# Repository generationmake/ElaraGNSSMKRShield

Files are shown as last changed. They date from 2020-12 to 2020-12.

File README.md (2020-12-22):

# ElaraGNSSMKRShield
GNSS Shield with Wuerth Elara for Arduino MKR

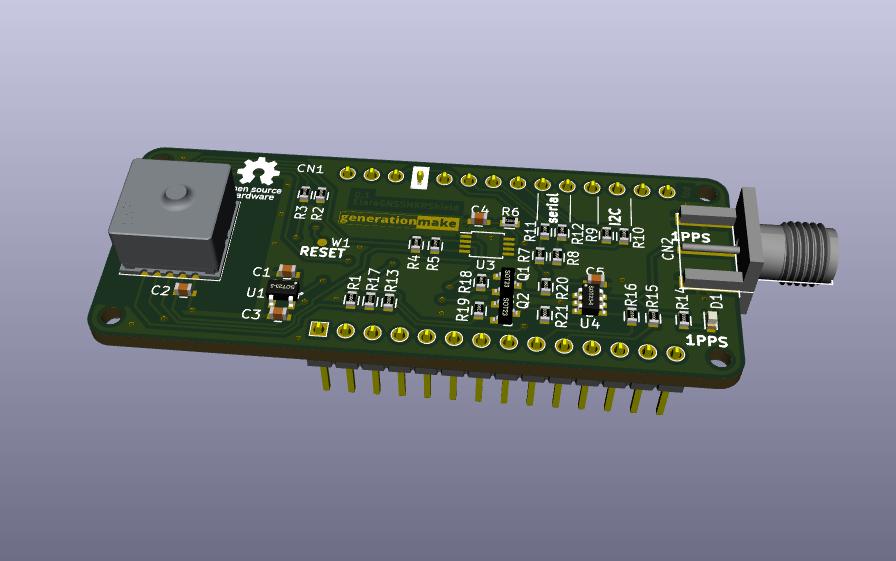
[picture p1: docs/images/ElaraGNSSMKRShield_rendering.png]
ElaraGNSSMKRShield rendering


## pin usage

### Arduino MKR connector CN1

| **Pin** | **Pin Name** | **Signal** | **Description** |
|:---:|:---:|:---:|:---:|
| 1 | AREF | | |
| 2 | DAC0/A0 | | |
| 3 | A1 | | |
| 4 | A2 | | |
| 5 | A3 | | |
| 6 | A4 | | |
| 7 | A5 | | |
| 8 | A6 | | |
| 9 | 0 | WAKE_UP | wake signal to Elara GNSS |
| 10 | 1 | 1PPS | 1PPS signal from Elara GNSS |
| 11 | 2 | | |
| 12 | 3 | | |
| 13 | 4 | | |
| 14 | 5 | ON_OFF | switch Elara GNSS on and off |
| 15 | 6 | | |
| 16 | 7 | | |
| 17 | 8/MOSI | | |
| 18 | 9/SCK | | |
| 19 | 10/MISO | | |
| 20 | 11/SDA | I2C_SDA | to Elara GNSS if I2C option is used |
| 21 | 12/SCL | I2C_SCL | to Elara GNSS if I2C option is used |
| 22 | 13/RX | SERIAL_RX | to Elara GNSS if serial option is used |
| 23 | 14/TX | SERIAL_TX | to Elara GNSS if serial option is used |
| 24 | RESET | | |
| 25 | GND | GND | |
| 26 | VCC | 3V3-rail | supply voltage for board |
| 27 | VIN | | |
| 28 | 5V0 | | |

### SMA connector CN2

SMA coax connector.

| **Pin** | **Signal** | **Description** |
|:---:|:---:|:---:|
| center  | 1PPS | |
| shield  | GND | |

## PCB

### Top

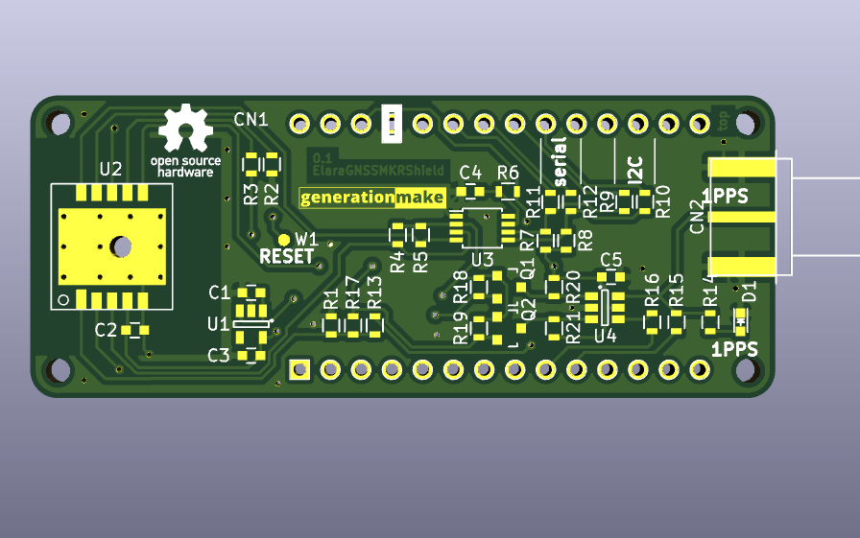
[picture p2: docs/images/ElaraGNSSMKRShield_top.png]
ElaraGNSSMKRShield PCB top


### Bottom

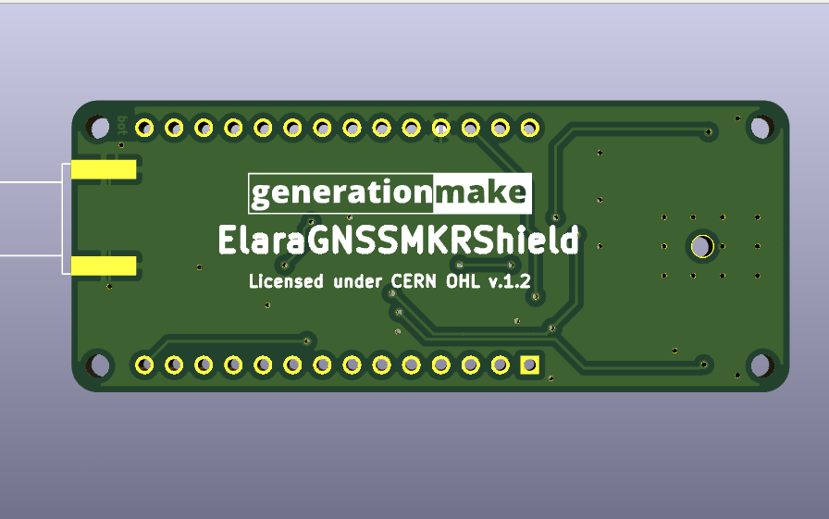
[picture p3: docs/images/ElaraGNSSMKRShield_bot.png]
ElaraGNSSMKRShield PCB bot


## Variants

By default the Elara GNSS is connected via I2C. It is possible to connect to serial.

### BOM changes

The following parts need to be changed:

| part | I2C variant | serial variant |
|:----:|:---:|:---:|
| R2 | 10k | DNI |
| R3 | DNI | 10k |
| R9 | 0R | DNI |
| R10  | 0R | DNI |
| R11  | DNI | 0R |
| R12  | DNI | 0R |

## Resources

### Datasheets

 * https://www.we-online.de/katalog/de/ELARA-I
 
 ### Arduino Libraries

* [107-Arduino-NMEA-Parser](https://github.com/107-systems/107-Arduino-NMEA-Parser)

## License

This hardware is licensed under the CERN OHL v. 1.2

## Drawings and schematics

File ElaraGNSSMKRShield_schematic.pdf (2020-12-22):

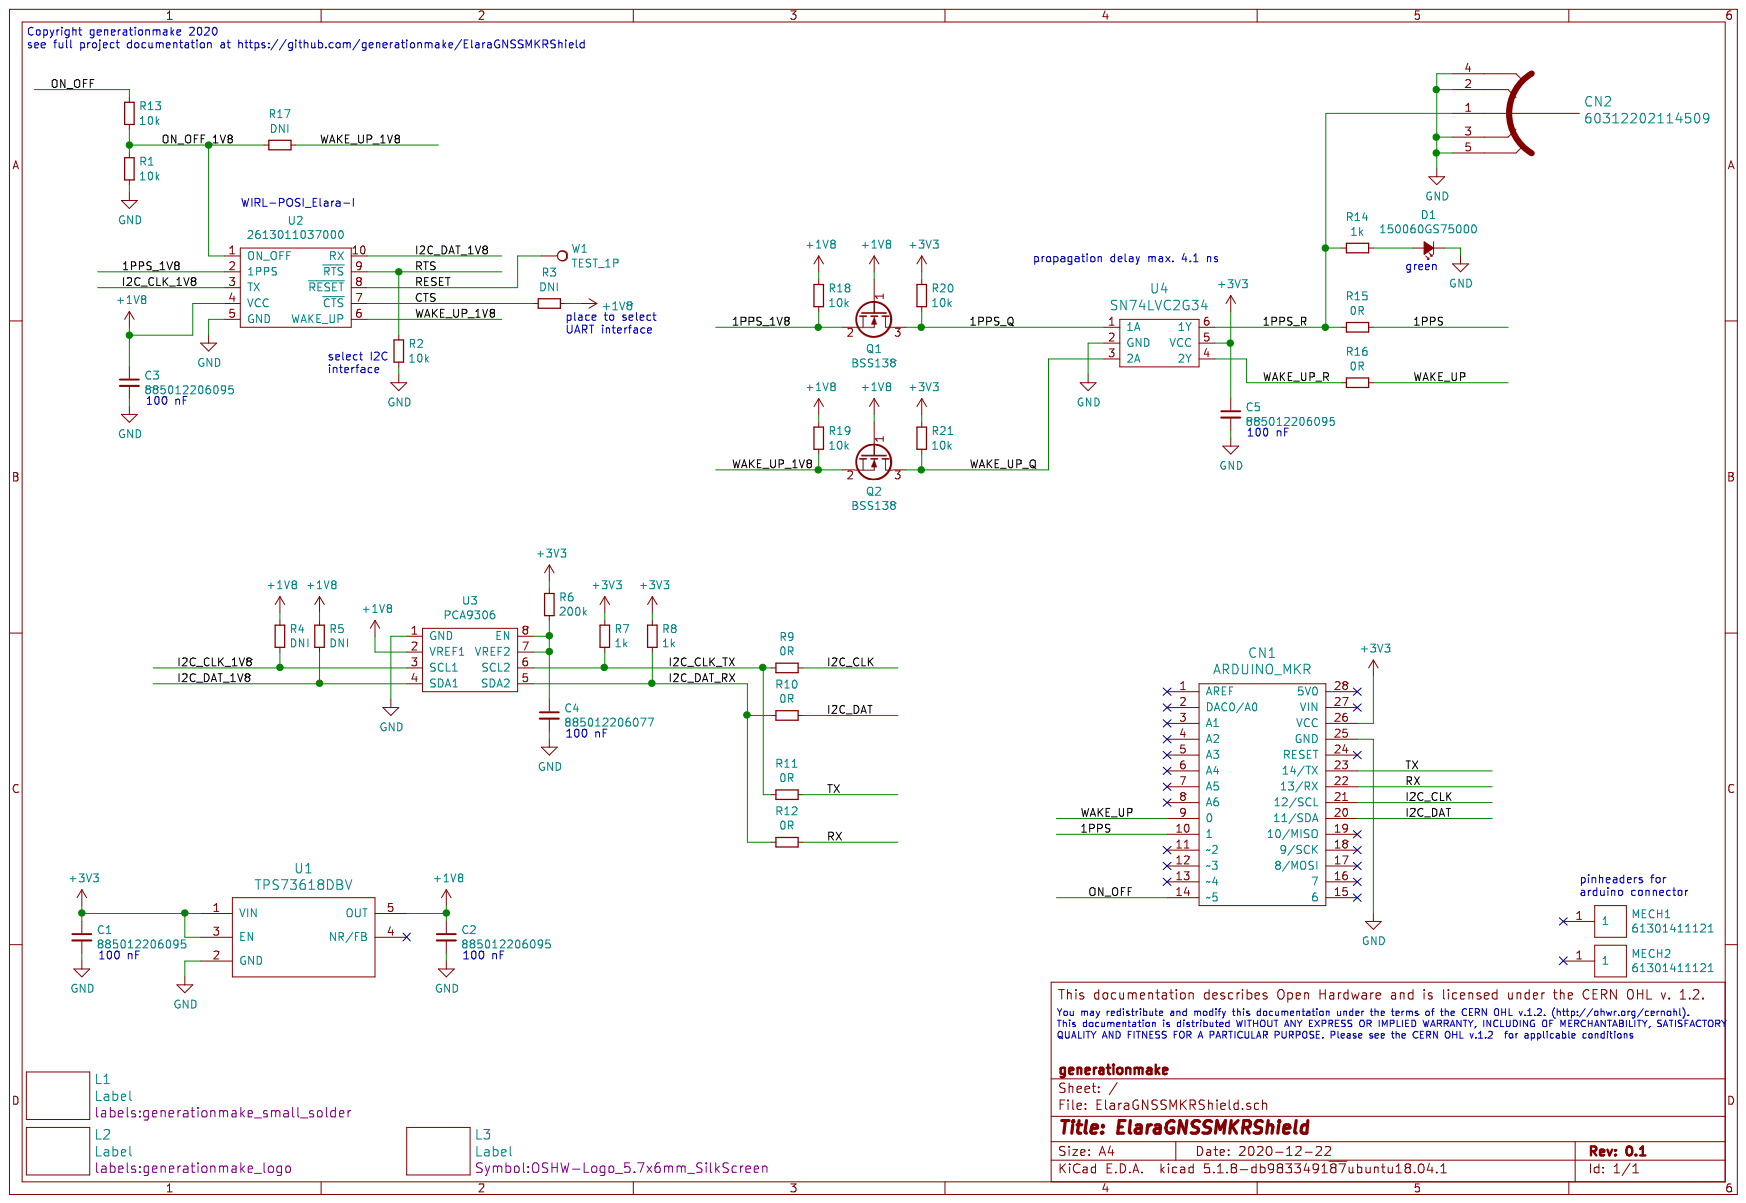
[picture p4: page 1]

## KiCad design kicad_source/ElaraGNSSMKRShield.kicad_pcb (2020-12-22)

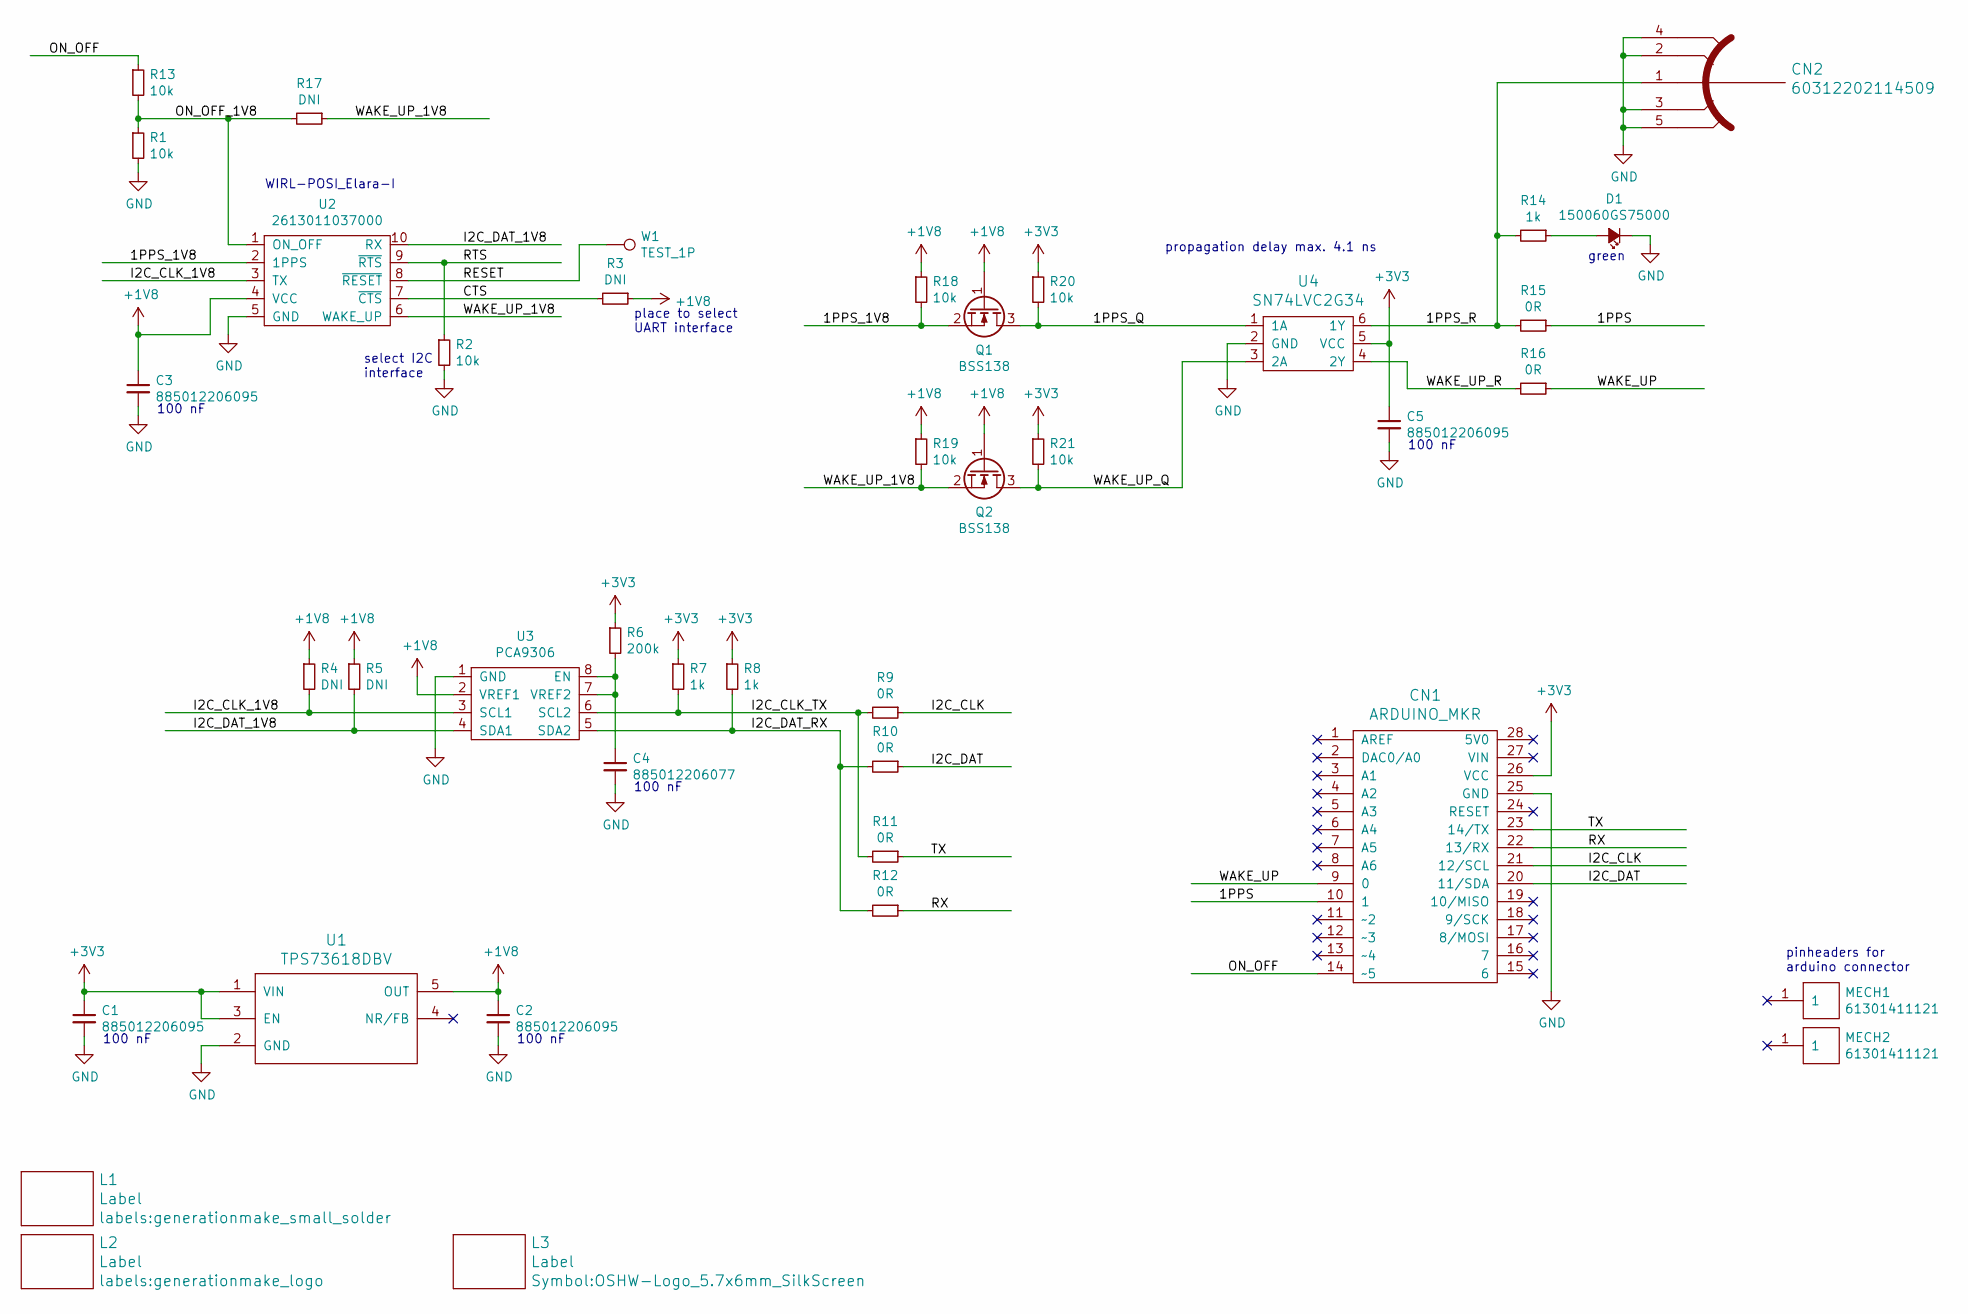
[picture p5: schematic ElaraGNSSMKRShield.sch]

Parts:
C1, C2, C3, C5: 885012206095; C_0603
C4: 885012206077; C_0603
CN1: ARDUINO_MKR; ARDUINO_MKR_HOLES_PINHEADER_EDGE
CN2: 60312202114509; WR-SMA-PCB
D1: 150060GS75000; LED_0603
L1: Label; generationmake_small_solder
L2: Label; generationmake_logo
L3: Label; OSHW-Logo_5.7x6mm_SilkScreen
MECH1, MECH2: 61301411121
Q1, Q2: BSS138; SOT-23
R1, R2, R13, R18, R19, R20, R21: 10k; R_0603
R3, R4, R5, R17: DNI; R_0603
R6: 200k; R_0603
R7, R8, R14: 1k; R_0603
R9, R10, R11, R12, R15, R16: 0R; R_0603
U1: TPS73618DBV; SOT-23-5
U2: 2613011037000; wuerth_WIRL-POSI_Elara-I
U3: PCA9306; TSSOP-8_3x3mm_Pitch0.65mm
U4: SN74LVC2G34; SOT-23-6
W1: TEST_1P; SolderWirePad_single_1mmSMD

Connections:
+1V8: C2.1, C3.1, Q1.1 (G), Q2.1 (G), R3.1, R4.1, R5.1, R18.1, R19.1, U1.5 (OUT), U2.4 (VCC), U3.2 (VREF1)
+3V3: C1.1, C5.1, CN1.26 (VCC), R6.1, R7.1, R8.1, R20.1, R21.1, U1.1 (VIN), U1.3 (EN), U4.5 (VCC)
/1PPS: CN1.10 (1), R15.1
/1PPS_1V8: Q1.2 (S), R18.2, U2.2 (1PPS)
/1PPS_Q: Q1.3 (D), R20.2, U4.1 (1A)
/1PPS_R: CN2.1, R14.2, R15.2, U4.6 (1Y)
/CTS: R3.2, U2.7 (~CTS)
/I2C_CLK: CN1.21 (12/SCL), R9.1
/I2C_CLK_1V8: R4.2, U2.3 (TX), U3.3 (SCL1)
/I2C_CLK_TX: R7.2, R9.2, R11.2, U3.6 (SCL2)
/I2C_DAT: CN1.20 (11/SDA), R10.1
/I2C_DAT_1V8: R5.2, U2.10 (RX), U3.4 (SDA1)
/I2C_DAT_RX: R8.2, R10.2, R12.2, U3.5 (SDA2)
/ON_OFF: CN1.14 (~~5), R13.1
/ON_OFF_1V8: R1.1, R13.2, R17.2, U2.1 (ON_OFF)
/RESET: U2.8 (~RESET), W1.1
/RTS: R2.1, U2.9 (~RTS)
/RX: CN1.22 (13/RX), R12.1
/TX: CN1.23 (14/TX), R11.1
/WAKE_UP: CN1.9 (0), R16.1
/WAKE_UP_1V8: Q2.2 (S), R17.1, R19.2, U2.6 (WAKE_UP)
/WAKE_UP_Q: Q2.3 (D), R21.2, U4.3 (2A)
/WAKE_UP_R: R16.2, U4.4 (2Y)
GND: C1.2, C2.2, C3.2, C4.2, C5.2, CN1.25 (GND), CN2.2, CN2.3, CN2.4, CN2.5, D1.1 (K), R1.2, R2.2, U1.2 (GND), U2.5 (GND), U3.1 (GND), U4.2 (GND)
unnamed: C4.1, R6.2, U3.7 (VREF2), U3.8 (EN)
unnamed: D1.2 (A), R14.1

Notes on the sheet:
select I2C interface
place to select UART interface
propagation delay max. 4.1 ns
green
100 nF
WIRL-POSI_Elara-I
pinheaders for arduino connector

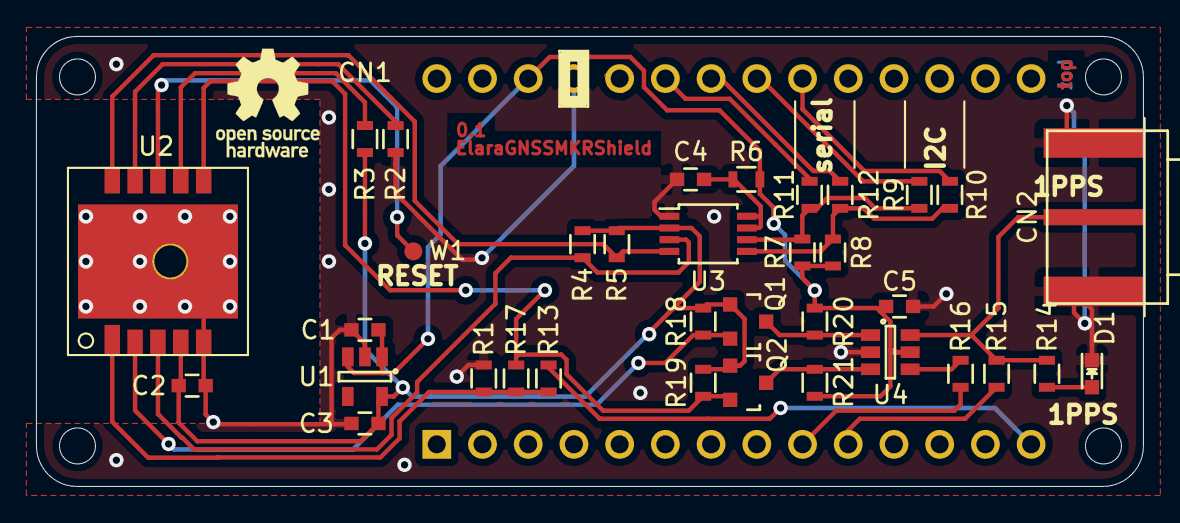
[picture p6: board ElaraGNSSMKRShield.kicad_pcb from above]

Board: 2 copper layers, 61.5 x 25.0 mm, 39 parts (1 on the bottom side), 26 nets.

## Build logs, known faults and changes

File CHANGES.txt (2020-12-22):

ElaraGNSSMKRShield - GNSS Shield with Wuerth Elara for Arduino MKR
see full project documentation at https://github.com/generationmake/ElaraGNSSMKRShield

changes

version 0.1 - 2020-12-22
* prototype release

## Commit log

2020-11-15 added kicad project
    [ElaraGNSSMKRShield.kicad_pcb, ElaraGNSSMKRShield.sch]
2020-11-15 updated schematic and board
    [ElaraGNSSMKRShield.kicad_pcb, ElaraGNSSMKRShield.sch]
2020-11-15 generated schematic pdf and image
2020-11-15 updated level shifter circuit
    [ElaraGNSSMKRShield.kicad_pcb, ElaraGNSSMKRShield.sch]
2020-11-16 beautified layout, added images, updated files
    [ElaraGNSSMKRShield.kicad_pcb, ElaraGNSSMKRShield.sch]
2020-12-21 added wuerth part numbers
    [ElaraGNSSMKRShield.kicad_pcb, ElaraGNSSMKRShield.sch]
2020-12-22 updated shape of PCB
    [ElaraGNSSMKRShield.kicad_pcb, ElaraGNSSMKRShield.sch]
2020-12-22 updated schematic pdf
    [ElaraGNSSMKRShield.sch]

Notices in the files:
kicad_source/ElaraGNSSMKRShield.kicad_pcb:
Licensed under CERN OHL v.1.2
